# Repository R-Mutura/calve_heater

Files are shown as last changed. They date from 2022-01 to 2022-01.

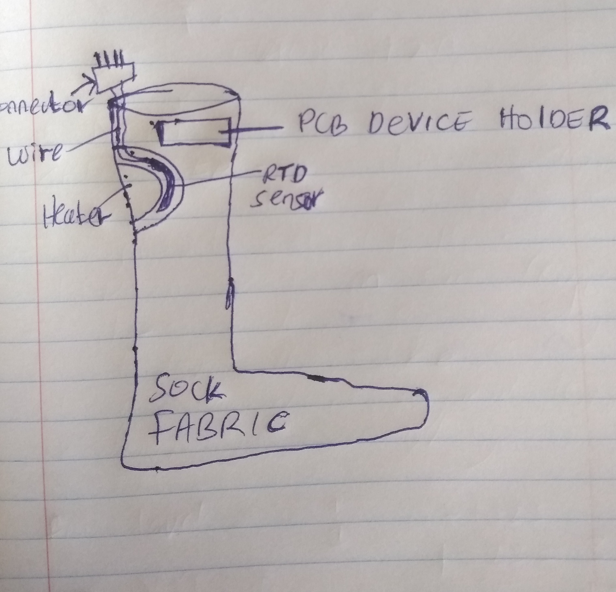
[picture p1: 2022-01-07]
hardware/ASSETS/IMG_20220107_123316.jpg

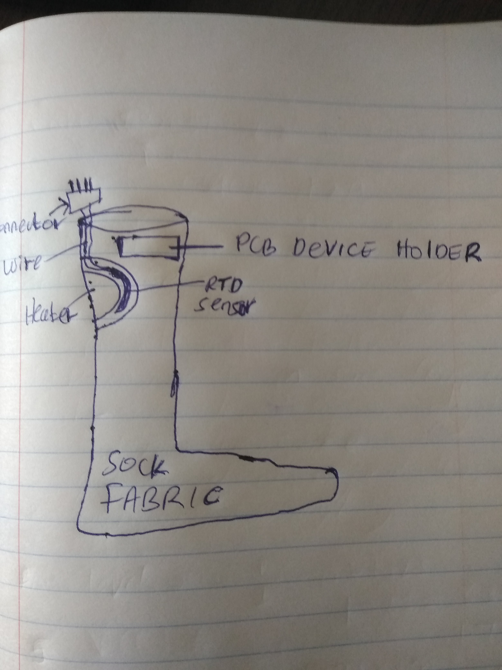
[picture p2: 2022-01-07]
hardware/ASSETS/IMG_20220107_123309.jpg

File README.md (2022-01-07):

# CALVE HEATER
This product features 3 main parts: the fabric containig a heater and  temperature RTD sensor embedded in it, a PCB that runs the heater and warming process and Firmware that is burnt in to the MCU located on the PCB assembly. 
The product features a modular approach where the controlling PCB can be plugged and unplugged from the fabric at will. It has a small form factor that allows it to be a hand held device that is powered via a Li-Po battery.

calve_heater

calve_heater 4

### How it works 🔧
THe PCB contains JST connectors from where the heater and temperature sensor are plugged into the board. Make sure thwy are plugged in. Press the ON button(left od USB) and the device wakes up and starsts the heating process. To turn off the device, Long press the ON button for about 1 sec. This will cause the device to go to sleep.
Temperature level setting is achieved via the use of the temperature button. (Button right of the USB). Default setting is at 40 degrees. Pressing it once increases the level to 44 deg, pressing it once again increases the level to 48 deg. Once at the highest level pressing the button again will take the level back to the initial  40 deg. The temperature level is indicated by use of the LED below the temperature button. 

- Green = 40deg
- Blue = 44deg
- Red = 48deg
<br>
The device uses PID control to warm up the fabric and maintain the desired temperature at all times ensuring safe.bumpless and comfortable use.
When the battery level gets too low the RED led flashes at 1 sec intervals indicating need for charging. 
the device is charged via the Micro-USB port. During charging, 2 leds below the on button are used for monitoring. Red is constantly on if its connected to power, and the Green LED indicates charging status:
- ON = CHarging
- OFF = Done charging <br>
<br>

# HARDWARE COMPONENTS
Heater [link](https://www.alibaba.com/product-detail/High-Temperature-Flexible-Ployimide-PI-Film_60627303766.html)   [link2](https://www.alibaba.com/product-detail/Thermostatic-electric-carbon-fiber-heating-element_62302051301.html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) <br>
Battery [link](https://www.indiamart.com/proddetail/lithium-ion-batteries-3-7v-2500mah-10433305048.html)  <br>
RTD sensor [link](https://www.digikey.com/en/products/detail/te-connectivity-measurement-specialties/R-8203/5277360)<br>
<br>
For the PCB components refer to the BOM folder in the hardware section.

# SAFETY
All the electrical components are on the PCB and can be disconnected in case of any critical situations by the user. Ensure to keep the device free from water and dust that may block the connectors. Disconnect the PCB device when washing the fabric. The Heater is a well made material wwith insulated wires to avoid shocking the user in amy way. When washing ensure not to cut, scrape or peel off any parts. Consider best practices [link](https://www.youtube.com/watch?v=5kIUcR_C9-A)

# BURNING BOOTLOADER AND FIRMWARE TO THE PCB
### Download the Files :arrow_down_small:
From this repo click on the download option at the code :arrow_double_down: 
- You will have two folders inside the main folder i.e 📁 Bootloader and  📁calve_heater_furmware
<br>
##  Burning bootload to the MCU :fire:
 <h3> Note: 
 DO THIS ON A WINDOWS OPERATING SYSTEM!!!
  </h3>
1) To do this you will need an older version of the arduino particularly version 1.6.9 find it here :link: [Old SoftwareReleases Arduino IDE](https://www.arduino.cc/en/main/OldSoftwareReleases) <br/>
2) Once you have it setup to burn the bootloader follow this tutotial keenly:link: [Burning Arduino Bootloader](https://create.arduino.cc/projecthub/techmirtz/arduino-without-external-clock-crystal-on-atmega328-d4fcc4) <br>
3) You can also use a USBASP to burn the bootloader. Note the above instruction will be used but instead of selecting arduino as ISP your programmer the USBASP is selected. 



[buy usbasp](https://aliexpress.ru/af/USBASP-USBISP-AVR-Programmer-USB.html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)
or here 
 :link: [buy usbasp](https://aliexpress.ru/item/32649685244.html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,searchweb201602_,searchweb201603_)
 <br/>
 
 ## Uploading the codes  :arrow_up:
 1) Open the 📁calve_heater_furmware Folder and open the INO file with your arduino
2) If you use Arduino as your programmer or an FTDI, Follow the instructions here from step 3: [Uploading Code](https://create.arduino.cc/projecthub/techmirtz/arduino-without-external-clock-crystal-on-atmega328-d4fcc4)
3) However if you are using a USBASP, Follow the following instructions:<br>
   a) Insert the ISP programmer cable socket onto ISP header. ...<br>
   b) Open Arduino IDE software. ...<br>
   c) Next, call out any example of source code. ...<br>
   d) Select “USBasp” from the Tools > Programmer menu.<br>
   e) Select “Upload using Programmer” from the File menu.<br>
 You can also explore more from the following tutorial :link:[How to Use USBasp Programmer with Arduino Boards](https://www.youtube.com/watch?v=ToKerwRR-70)

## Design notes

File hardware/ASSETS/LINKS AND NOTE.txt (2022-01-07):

FLEXIBLE HEATERS: 
COTTON TYPE HEATER:
https://www.alibaba.com/product-detail/China-factory-made-carbon-fiber-heating_62332728192.html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
https://www.alibaba.com/product-detail/Thermostatic-electric-carbon-fiber-heating-element_62302051301.html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
USED+++=====
https://www.alibaba.com/product-detail/High-Temperature-Flexible-Ployimide-PI-Film_60627303766.html  -0.4W

TEMP SENSOR:
https://www.digikey.com/en/products/detail/te-connectivity-measurement-specialties/R-8203/5277360
CAN EASILY BE PLACED IN THE FABRIC.

BATTERY:https://www.indiamart.com/proddetail/lithium-ion-batteries-3-7v-2500mah-10433305048.html

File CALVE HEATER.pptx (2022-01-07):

## CALVE HEATER

DETAILED ESCRIPTION

## PCB

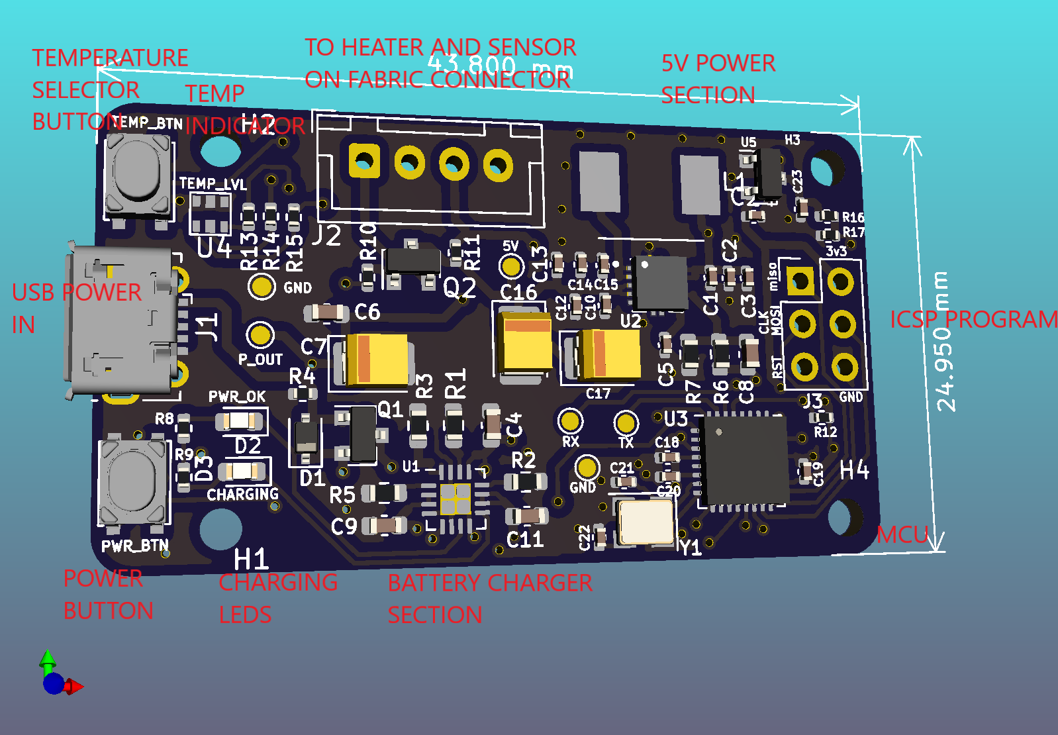
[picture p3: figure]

## PCB

- The USB port acts as the charging input. When charging the charging LEDs, green and Red are on. When done with charging, Only the red LED is on. (note the location of the charging LEDs.
- The Power button is used to turn on and off the device. Press once to turn on and long Press for 1 sec to turn off.
- Temperature selector button is used to set the temperature level for which the heater is to operate. Defult is 40 deg. Press once to increase the level to 44deg then again to 48 deg. Once at maximum pressing the button returns t=the temperature setting to the default 40deg.

## PCB

- The connector labeled J2 is used to connect the heater coil/element located off the board(in the fabric). As well as the temperature sensor. This allows the heater and sensor to be plugged in and removeable at will and depending on use.
- ICSP programmer are used to load the software to the board MCU as per the instruction in the github link.
- The MCU controls the heating of the board accordingly ensuring that it measures the temperature in of the heater using the connected sensor and maintains the heat as desired. It ensures that the desired temperature and over temperature conditions do not occur. this MCU control/drives the heater.
- The MCU as well reads the user settings and manages the LEDS indicators that inform the user.

## PCB

- EG when the battery is Low, the MCU causes the red LED to blink at a rate of 1 sec to indicate need for charging.
- Temperature indicator LED are 3 which will indicate the 3 temperature setting selected by the user:
- Green = 40deg low
- Blue = 44deg medium
- Red = 48deg high

## PCB

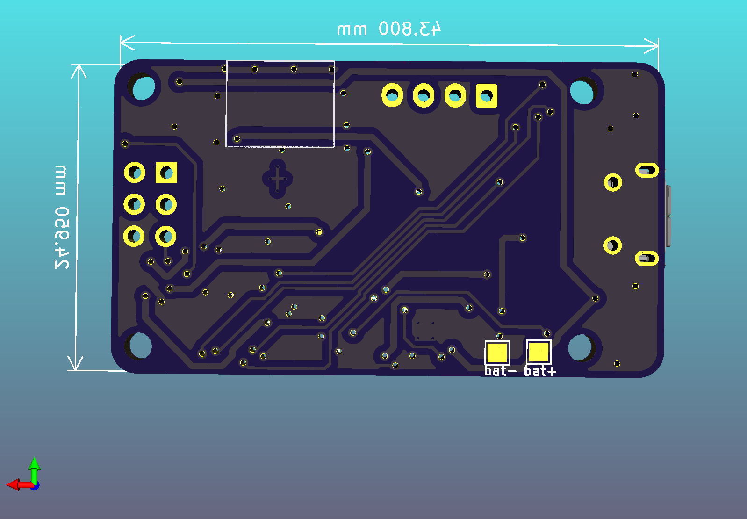
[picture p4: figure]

## BATTERY

- He battery is connected to the PCB via the bat+ and bat- pads shown above. These two terminal allow flexibility of connection and placement of the battery on any angle in a mechanical package.
- Battery type for use: https://www.indiamart.com/proddetail/lithium-ion-batteries-3-7v-2500mah-10433305048.html

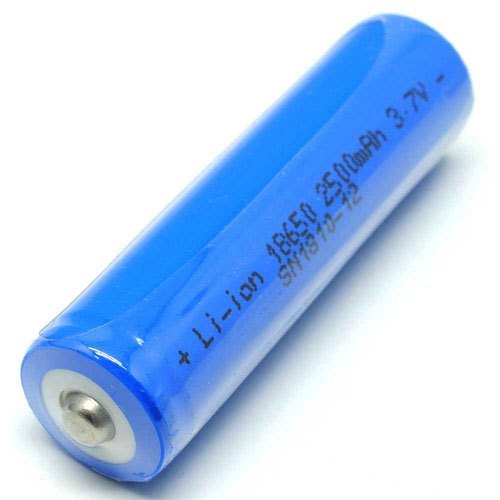
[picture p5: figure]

## BATTERY LIFE

- The design is kept simple and efficient as possible using low quiescent IC and MCUs. The heater power range is as well low with a about 100mA current consumption. Thus the total current consumption range for all the equipment in the PCB is about
- 100 heater + 100 MCU+ 50 Loses=250mA
- Battery capacity = 2500
- Total Hours of use = 2500/250 = 10Hrs approximate battery life.

## HEATER LAYOUT SKETCH

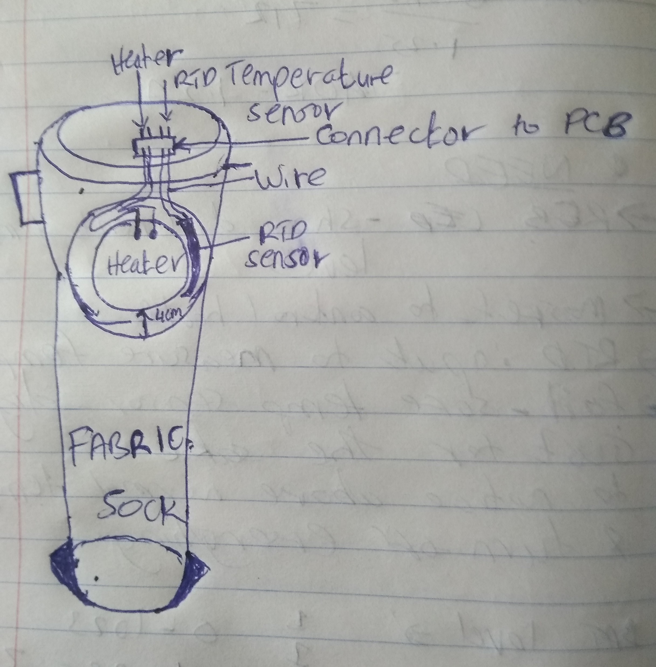
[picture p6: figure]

## HEATER SELECTION

- COTTON TYPE HEATER LINK : https://www.alibaba.com/product-detail/Thermostatic-electric-carbon-fiber-heating-element_62302051301.html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
- Flexible heater selection 2: https://www.alibaba.com/product-detail/High-Temperature-Flexible-Ployimide-PI-Film_60627303766.html

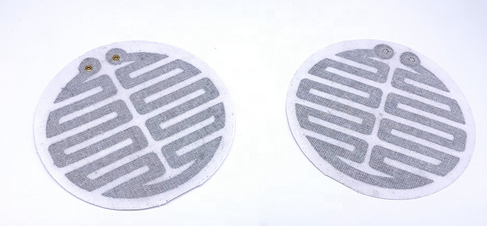
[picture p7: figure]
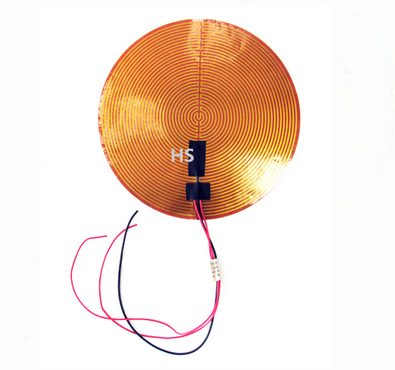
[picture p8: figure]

## TEMPERATURE SENSOR

- https://www.digikey.com/en/products/detail/te-connectivity-measurement-specialties/R-8203/5277360
- Flexible and bendable surface which is easy to integrate/place in a fabric

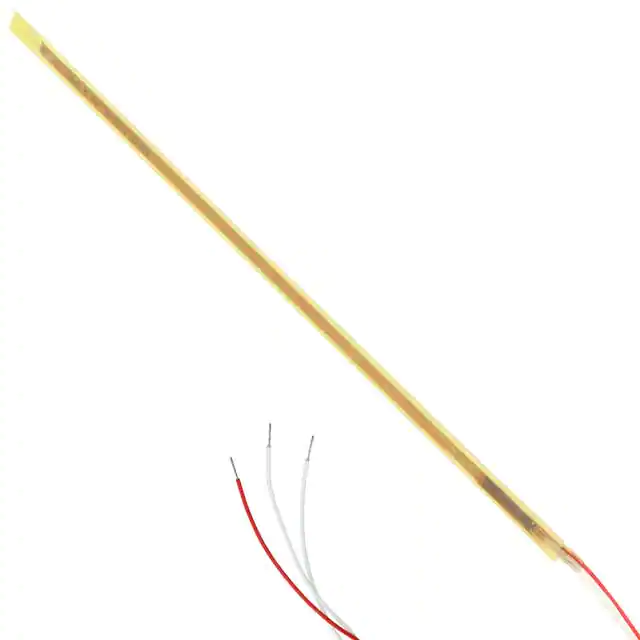
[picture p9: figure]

## SAFETY

- The product features a removeable PCB device which can there fore be kept odd any harmful conditions e.g. during washing.
- The heater elements by nature of there design are well insulated and suited to be used in fabrics and thus have good insulation resistant to corrosion and able to be bent and folded according to best practice in any electrically heated fabrics.
- The RTD sensor is well insulated as well and carries micro amperes of current which cannot lead to any form of sensation or shock to the user incase of any leakages. Making this product perfectly safe for use.

## CONCLUSION

- The product design utilizes existing components and materials that a re cheaply available making it affordable.
- The PCB design is of a small form factor and flexible thus making it very adaptable and to any changing conditions and uses.
- The battery life in this design is optimized via design of efficient software, hardware components and the heating process.
- Safety is integrated in the process from firmware design to prevent over temperature conditions and proper selection of heating and sensor elements.
- Rechargeable battery and proper indication has been achieved in the design as well.

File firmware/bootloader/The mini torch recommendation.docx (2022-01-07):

The mini torch recommendation

LED

1. R2835W-W5M-Q20 : https://www.luckylight.cn/en/products/lighting-led/mid-power-led/r2835w-w5m-q20/ (60mA 0.2W LED)__midpower range
2. https://www.digikey.com/en/products/filter/led-lighting-white/124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

Time IC

We ‘ll use ATMega32u chip which is present in Arduino Micro and Leonardo Arduino boards.

(We will have to introduce sleep function and the two buttons to act as the interrupt to wake up the IC once time needs to be set and also to wake up the IC to display clock time). Thus reduce power consumption significantly.

An RTC IC with a small form factor e.g. Maxim Integrated DS3231MZ+TRL which is also very accurate

Crystal oscillators for the atmega is not needed (configured to be the internal clock by the bootloader) and for the RTC=32KHz.

Boot loading instructions: https://www.instructables.com/Burn-a-New-Bootloader-Arduino-Pro-Mini/

LCD screen

The smallest OLED screen that uses I2C e.g. 0.69 inch screen https://africa.rsdelivers.com/product/midas/mcot096016ay-wi/midas-069in-white-passive-matrix-oled-display-96-x/8235948

Button to turn light on/off – Well use normal push buttons and implement a software toggle.

And to write to the output to turn on the LEDS, well use a MOSFET (N_MOS) WST02N10: https://lcsc.com/product-detail/MOSFETs_Winsok-Semicon-WST02N10_C148341.html

Also for the time setting button we will use a normal button in conjunction with ezButton library to handle different event like button press, double press and long press

Battery

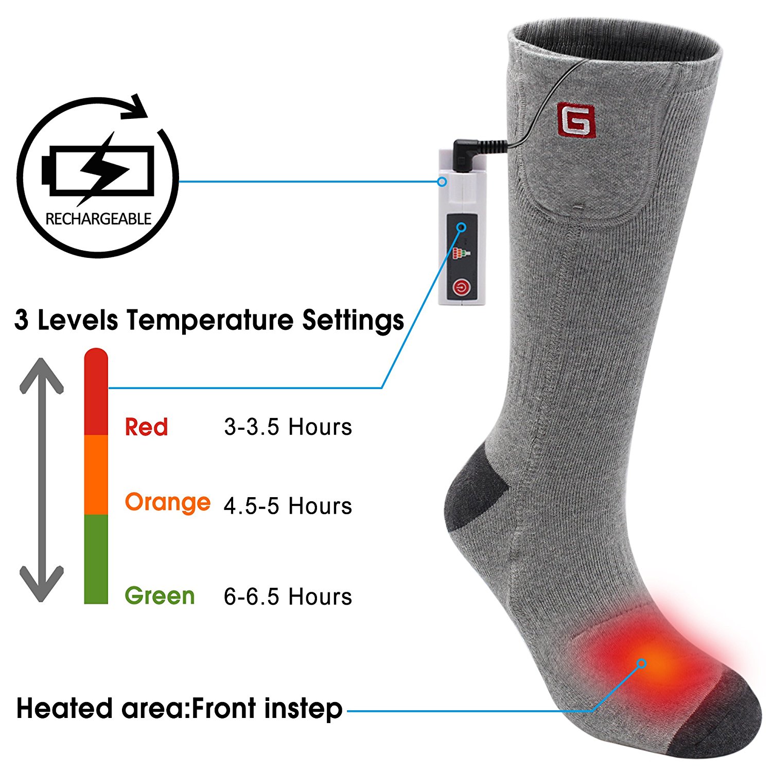
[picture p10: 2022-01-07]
hardware/ASSETS/Global-Vasion-Rechargeable-Battery-Heated-Socks-02.jpg

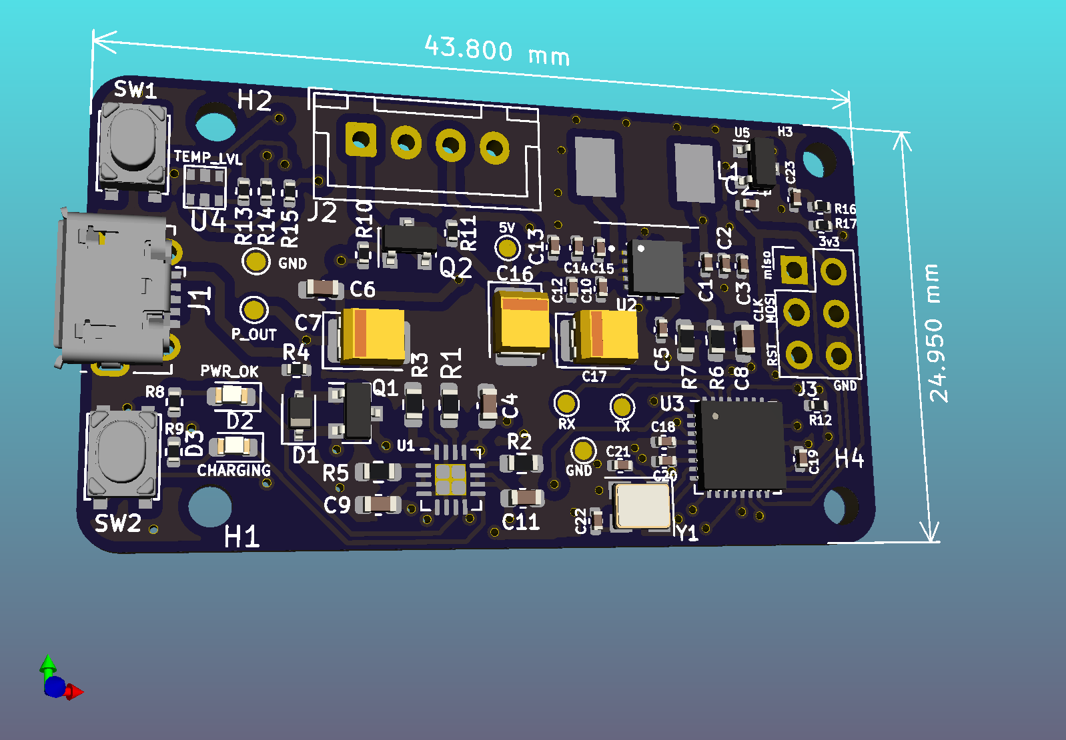
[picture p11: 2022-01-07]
hardware/png/calve_heater 6.png

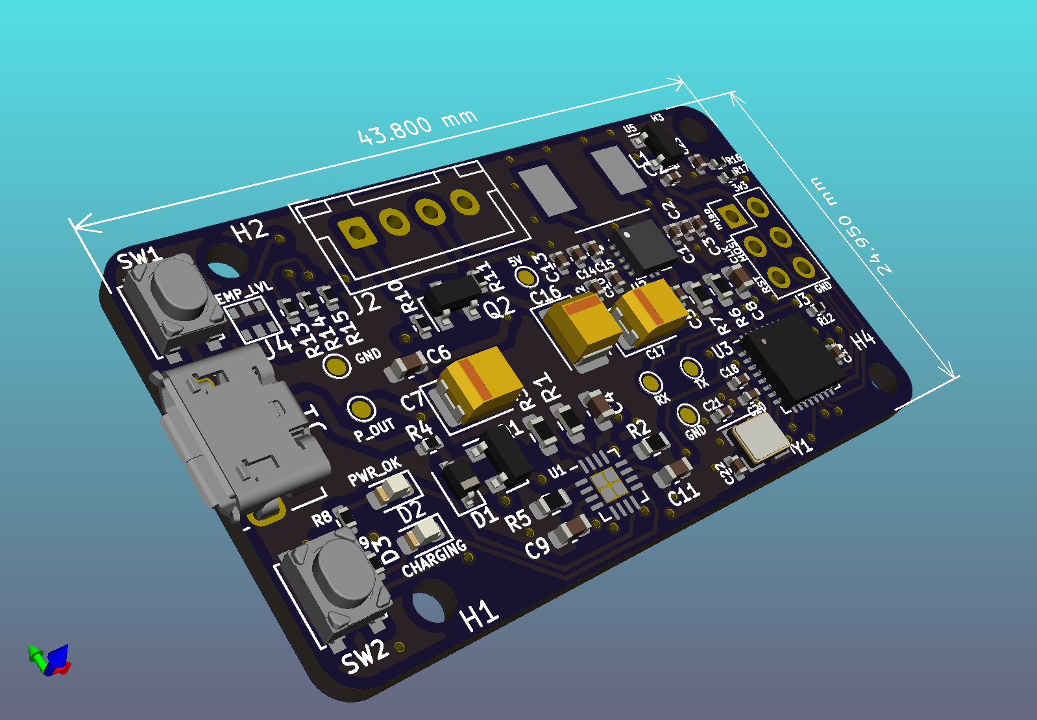
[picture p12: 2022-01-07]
hardware/png/calve_heater 4.png

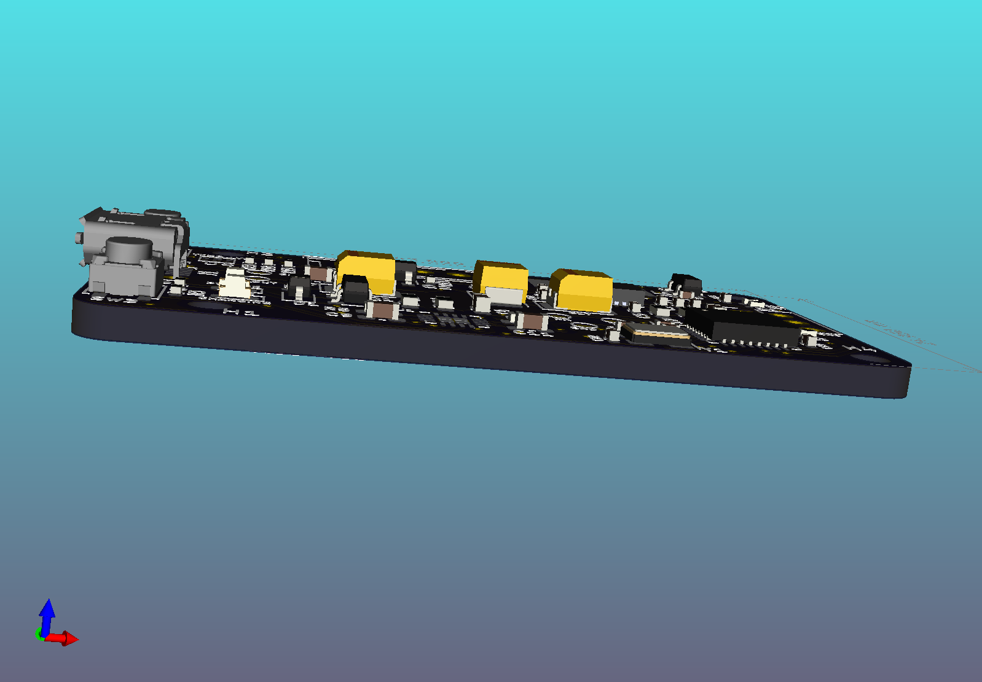
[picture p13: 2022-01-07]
hardware/png/calve_heater 3.png

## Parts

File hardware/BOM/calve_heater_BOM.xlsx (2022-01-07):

Reference | Value | Footprint | MPN | Vendor | QTY
C1-C3, C23, C24 | 10u | Capacitor_SMD:C_0402_1005Metric | JMK105CBJ106MV-F | LCSC | 5
C4 | 1u | Capacitor_SMD:C_0603_1608Metric | FS18B105K160PBG | LCSC | 1
C5 | 10n | Capacitor_SMD:C_0402_1005Metric | C0402X7R103K500NTB | LCSC | 1
C6 | 4.7u | Capacitor_SMD:C_0603_1608Metric | GRM188R61C475KE11D | LCSC | 1
C8 | 18p | Capacitor_SMD:C_0603_1608Metric | CGA3E2C0G1H180JT0Y0N | LCSC | 1
C9, C11 | 10u | Capacitor_SMD:C_0603_1608Metric | CL10A106MA8NRNC | LCSC | 2
C10, C12-C15 | 4.7u | Capacitor_SMD:C_0402_1005Metric | EDK105BBJ475MVLF | LCSC | 5
C7, C16, C17 | 100u | Capacitor_Tantalum_SMD:CP_EIA-3528-21_Kemet-B | CA45-B-10V-100uF-M | LCSC | 3
C18-C20 | 100nF | Capacitor_SMD:C_0402_1005Metric | C0402X7R104K160NTB | LCSC | 3
C21, C22 | 22pF | Capacitor_SMD:C_0402_1005Metric | GRM1555C1H220JA01D | LCSC | 2
D1 | D_Schottky_Small | Diode_SMD:D_SOD-323 | BAT60B | LCSC | 1
D2 | GREEN | LED_SMD:LED_0603_1608Metric | HSMG-C190 | Digikey | 1
D3 | RED | LED_SMD:LED_0603_1608Metric | LTST-C190KRKT | Digikey | 1
J1 | USB_B_Micro | Connector_USB:USB_Micro-B_Molex-105017-0001 | 105017-0001 | Digikey | 1
J2 | Conn_out | Connector_JST:JST_XH_B4B-XH-A_1x04_P2.50mm_Vertical | S4B-XH-SM4-TB(LF)(SN) | Digikey | 1
J3 | ICSP_HEADER | Connector_PinHeader_2.54mm:PinHeader_2x03_P2.54mm_Vertical | C65114 | LCSC | 1
L1 | 1.5uH | greencharge-footprints:MWSA0518S-1R5MT | MWSA0518S-1R5MT | LCSC | 1
Q1 | FDN338P-NL | Package_TO_SOT_SMD:SOT-23 | AP3401 | LCSC | 1
Q2 | SI2304BDS-T1-GE3 | Package_TO_SOT_SMD:SOT-23 | SI2304BDS-T1-GE3 | LCSC | 1
R1 | 50k | Resistor_SMD:R_0603_1608Metric | RC0603FR-0747KL | LCSC | 1
R2 | 1.07k | Resistor_SMD:R_0603_1608Metric | RCT031K07FLF | LCSC | 1
R3 | 750R | Resistor_SMD:R_0603_1608Metric | AECR0603F750RK9 | LCSC | 1
R4 | 10k | Resistor_SMD:R_0402_1005Metric | RC0402FR-7W10KL | LCSC | 1
R5 | 10k | Resistor_SMD:R_0603_1608Metric | ERJPA3J103V | LCSC | 1
R6 | 402k | Resistor_SMD:R_0603_1608Metric | 0603WAF4023T5E | LCSC | 1
R7 | 100k | Resistor_SMD:R_0603_1608Metric | RC0603FR-07100KL | LCSC | 1
R8, R9 | 1k | Resistor_SMD:R_0402_1005Metric | RC-02W1001FT | LCSC | 2
R10, R11 | 150R | Resistor_SMD:R_0402_1005Metric | 0402WGF1500TCE | LCSC | 2
R12 | 4.7K | Resistor_SMD:R_0402_1005Metric | RC0402FR-074K7L | LCSC | 1
R13-R17 | 1K | Resistor_SMD:R_0402_1005Metric | RC-02W1001FT | LCSC | 5
SW1, SW2 | SW_Push | greencharge-footprints:SKRPACE010 | SKRPACE010 | LCSC | 2
U1 | BQ24075RGT | Package_DFN_QFN:VQFN-16-1EP_3x3mm_P0.5mm_EP1.68x1.68mm_ThermalVias | BQ24075RGTR | LCSC | 1
U2 | TPS61230DRCR | greencharge-footprints:VREG_V62_16624-01YE | TPS61230DRCR | LCSC | 1
U3 | ATmega328P-MU | Package_DFN_QFN:QFN-32-1EP_5x5mm_P0.5mm_EP3.1x3.1mm | ATmega328P-MU | Digipart | 1
U4 | EAST1616RGBA8 | greencharge-footprints:EAST1616RGBA8 | EAST1616RGBA8 | Digikey | 1
U5 | LM1117-3.3 | Package_TO_SOT_SMD:SOT-23 | LP3986-33B3F | LCSC | 1
Y1 | X322516MOB4SI | Crystal:Crystal_SMD_EuroQuartz_MT-4Pin_3.2x2.5mm | X322516MOB4SI | LCSC | 1

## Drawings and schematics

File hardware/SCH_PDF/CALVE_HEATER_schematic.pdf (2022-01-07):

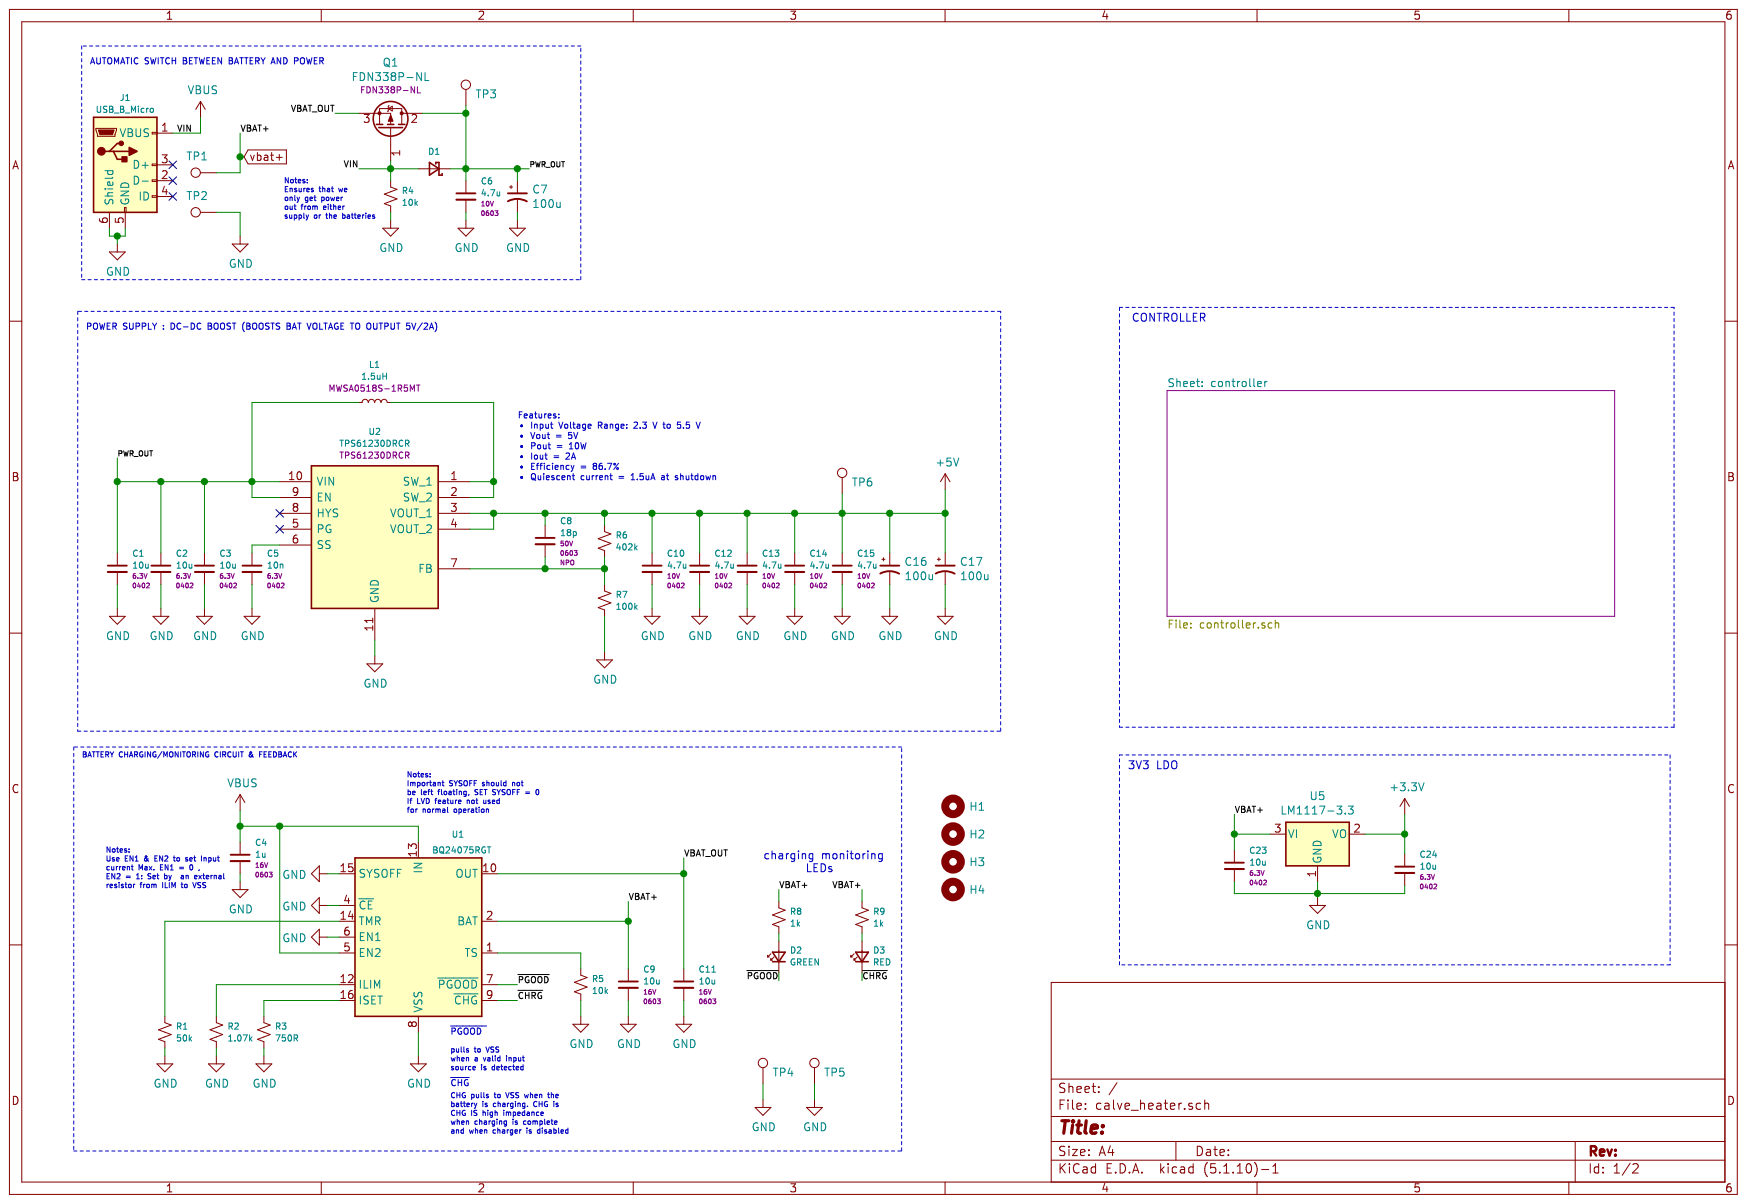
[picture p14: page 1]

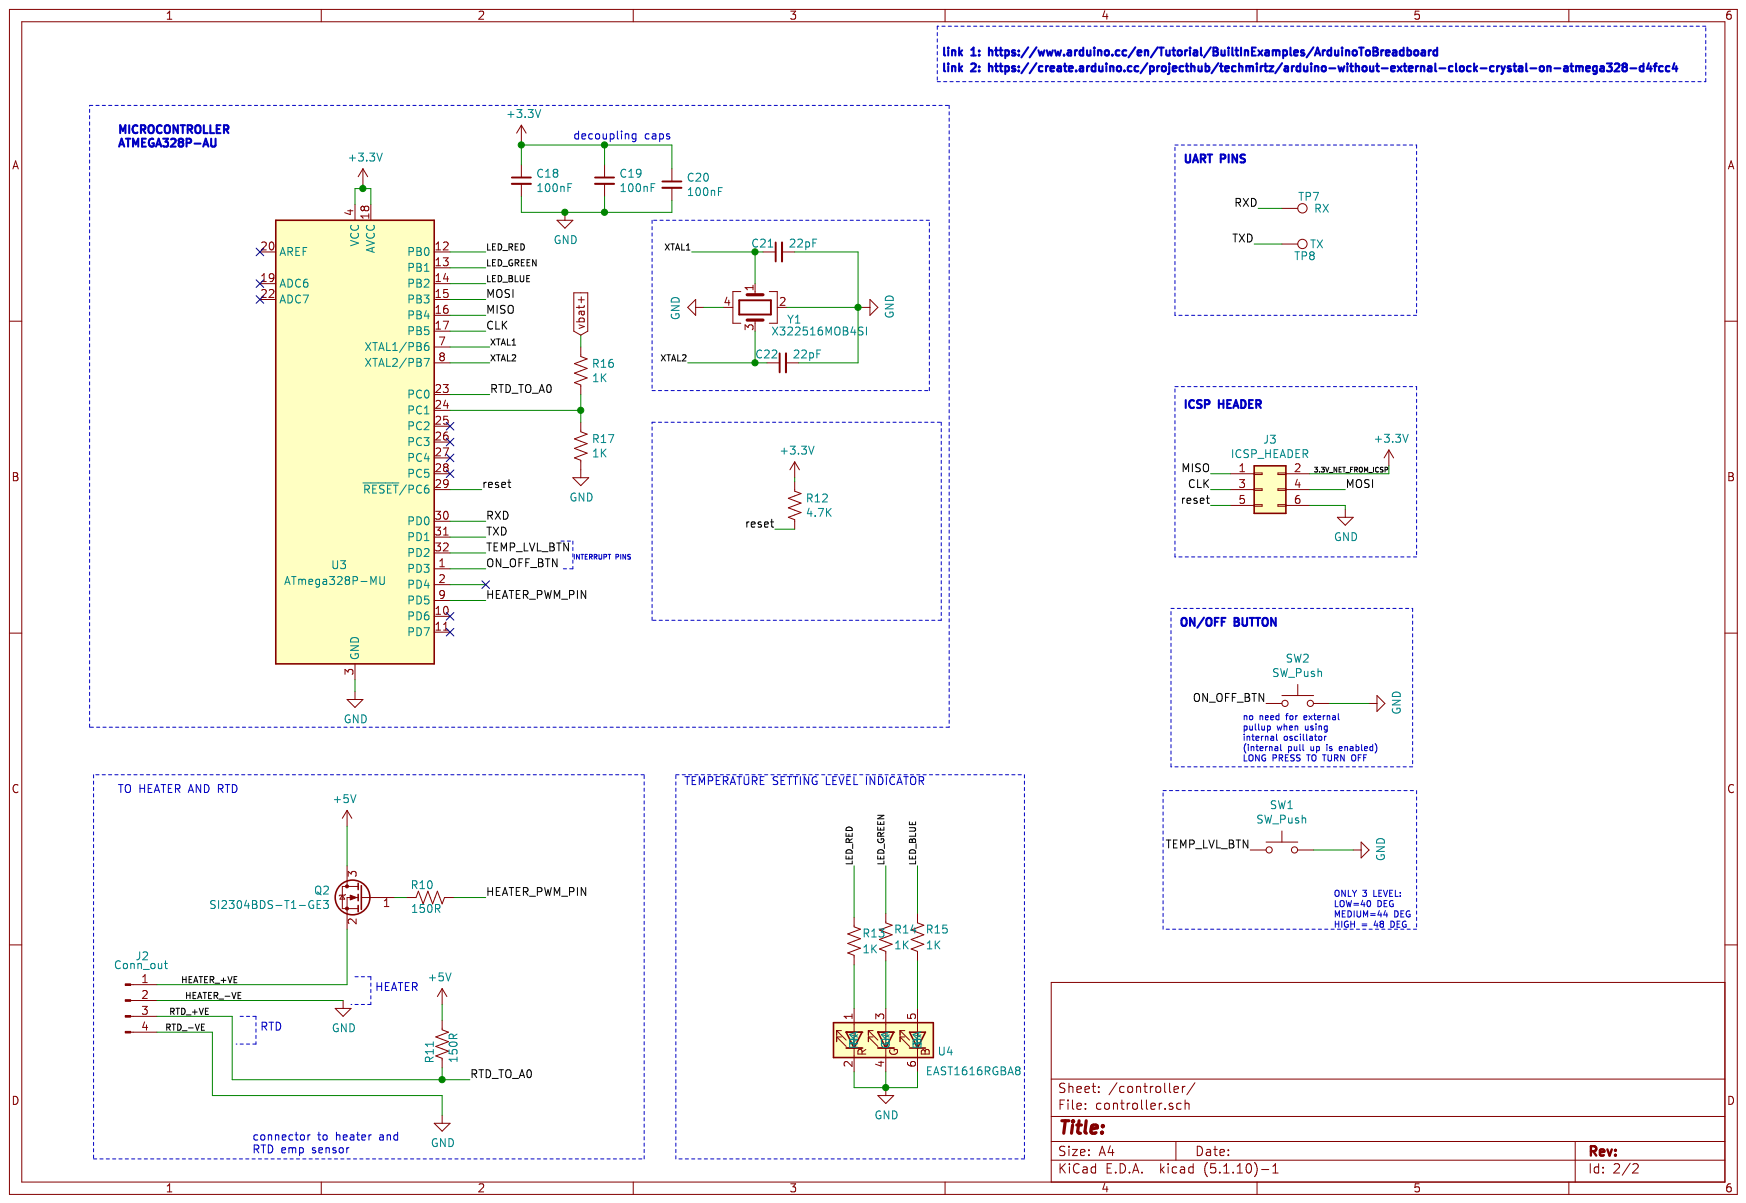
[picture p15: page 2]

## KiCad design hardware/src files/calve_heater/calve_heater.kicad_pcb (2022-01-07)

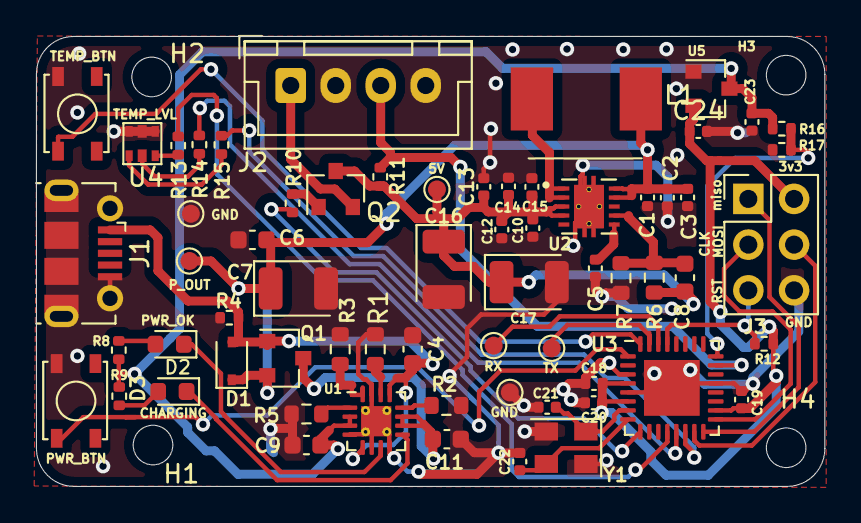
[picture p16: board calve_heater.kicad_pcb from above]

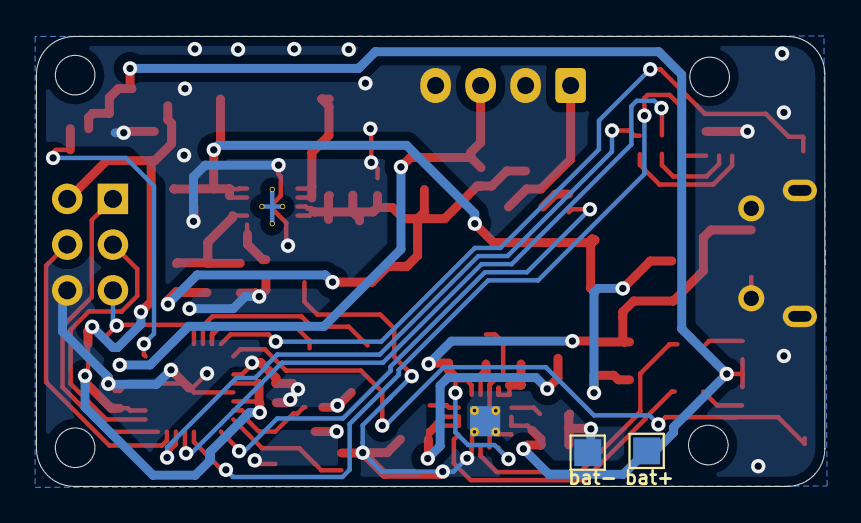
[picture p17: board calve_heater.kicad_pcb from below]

Board: 2 copper layers, 43.8 x 25.0 mm, 70 parts (2 on the bottom side), 39 nets.

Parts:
5V: TestPoint; TestPoint_Pad_D1.0mm
C1, C2, C3, C23, C24: 10u; C_0402_1005Metric
C4: 1u; C_0603_1608Metric
C5: 10n; C_0402_1005Metric
C6: 4.7u; C_0603_1608Metric
C7, C16, C17: 100u; CP_EIA-3528-21_Kemet-B
C8: 18p; C_0603_1608Metric
C9, C11: 10u; C_0603_1608Metric
C10, C12, C13, C14, C15: 4.7u; C_0402_1005Metric
C18, C19, C20: 100nF; C_0402_1005Metric
C21, C22: 22pF; C_0402_1005Metric
D1: D_Schottky_Small; D_SOD-323
D2: GREEN; LED_0603_1608Metric
D3: RED; LED_0603_1608Metric
GND: TestPoint; TestPoint_Pad_D1.0mm
GND#2: TestPoint; TestPoint_Pad_D1.0mm
H1, H2, H3, H4: MountingHole; MountingHole_2.2mm_M2_ISO14580
J1: USB_B_Micro; USB_Micro-B_Molex-105017-0001
J2: Conn_out; JST_XH_B4B-XH-A_1x04_P2.50mm_Vertical
J3: ICSP_HEADER; PinHeader_2x03_P2.54mm_Vertical
L1: 1.5uH; MWSA0518S-1R5MT
PWR_BTN: SW_Push; SKRPACE010
P_OUT: TestPoint; TestPoint_Pad_D1.0mm
Q1: FDN338P-NL; SOT-23
Q2: SI2304BDS-T1-GE3; SOT-23
R1: 50k; R_0603_1608Metric
R2: 1.07k; R_0603_1608Metric
R3: 750R; R_0603_1608Metric
R4: 10k; R_0402_1005Metric
R5: 10k; R_0603_1608Metric
R6: 402k; R_0603_1608Metric
R7: 100k; R_0603_1608Metric
R8, R9: 1k; R_0402_1005Metric
R10, R11: 150R; R_0402_1005Metric
R12: 4.7K; R_0402_1005Metric
R13, R14, R15, R16, R17: 1K; R_0402_1005Metric
RX: RX; TestPoint_Pad_D1.0mm
TEMP_BTN: SW_Push; SKRPACE010
TX: TX; TestPoint_Pad_D1.0mm
U1: BQ24075RGT; VQFN-16-1EP_3x3mm_P0.5mm_EP1.68x1.68mm_ThermalVias
U2: TPS61230DRCR; VREG_V62_16624-01YE
U3: ATmega328P-MU; QFN-32-1EP_5x5mm_P0.5mm_EP3.1x3.1mm
U4: EAST1616RGBA8
U5: LM1117-3.3; SOT-23
Y1: X322516MOB4SI; Crystal_SMD_EuroQuartz_MT-4Pin_3.2x2.5mm
bat+: TestPoint; TestPoint_Pad_1.5x1.5mm
bat-: TestPoint; TestPoint_Pad_1.5x1.5mm

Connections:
+3V3: C18.1, C19.1, C20.1, C24.1, J3.2, R12.1, U3.4, U3.6, U3.18, U5.2
+5V: 5V.1, C8.1, C10.1, C12.1, C13.1, C14.1, C15.1, C16.1, C17.1, Q2.3, R6.1, R11.2, U2.3, U2.4
/PWR_OUT: C1.1, C2.1, C3.1, C6.1, C7.1, D1.1, L1.1, P_OUT.1, Q1.2, U2.9, U2.10
/VBAT_OUT: C11.1, Q1.3, U1.10, U1.11
/controller/CLK: J3.3, U3.17
/controller/HEATER_+VE: J2.1, Q2.2
/controller/HEATER_PWM_PIN: R10.2, U3.9
/controller/LED_BLUE: R15.1, U3.14
/controller/LED_GREEN: R14.1, U3.13
/controller/LED_RED: R13.1, U3.12
/controller/MISO: J3.1, U3.16
/controller/MOSI: J3.4, U3.15
/controller/ON_OFF_BTN: PWR_BTN.1, U3.1
/controller/RTD_+VE: J2.3, R11.1, U3.23
/controller/RXD: RX.1, U3.30
/controller/TEMP_LVL_BTN: TEMP_BTN.1, U3.32
/controller/TXD: TX.1, U3.31
/controller/XTAL1: C21.1, U3.7, Y1.1
/controller/XTAL2: C22.1, U3.8, Y1.3
/controller/reset: J3.5, R12.2, U3.29
/~CHRG: D3.1, U1.9
/~PGOOD: D2.1, U1.7
GND: C1.2, C2.2, C3.2, C4.2, C5.2, C6.2, C7.2, C9.2, C10.2, C11.2, C12.2, C13.2, C14.2, C15.2, C16.2, C17.2, C18.2, C19.2, C20.2, C21.2, C22.2, C23.2, C24.2, GND.1, GND#2.1, J1.5, J1.6, J2.2, J2.4, J3.6, PWR_BTN.2, R1.2, R2.2, R3.2, R4.2, R5.2, R7.2, R17.2, TEMP_BTN.2, U1.4, U1.6, U1.8, U1.15, U1.17, U2.11, U3.3, U3.5, U3.21, U3.33, U4.2, U4.4, U4.6, U5.1, Y1.2, Y1.4, bat-.1
unnamed: C5.1, U2.6
unnamed: C8.2, R6.2, R7.1, U2.7
unnamed: D2.2, R8.2
unnamed: D3.2, R9.2
unnamed: L1.2, U2.1, U2.2
unnamed: Q2.1, R10.1
unnamed: R1.1, U1.14
unnamed: R2.1, U1.12
unnamed: R3.1, U1.16
unnamed: R5.1, U1.1
unnamed: R13.2, U4.1
unnamed: R14.2, U4.3
unnamed: R15.2, U4.5
unnamed: R16.2, R17.1, U3.24
VBUS: C4.1, D1.2, J1.1, Q1.1, R4.1, U1.5, U1.13
vbat+: C9.1, C23.1, R8.1, R9.1, R16.1, U1.2, U1.3, U5.3, bat+.1

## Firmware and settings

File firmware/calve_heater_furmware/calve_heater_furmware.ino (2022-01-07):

#include <Arduino.h>
#include <OneButton.h>
#include "LowPower.h"

//initialize the 2 buttons
#define TEMP_LVL_BTN 3  //PD3
   OneButton btn = OneButton(
        TEMP_LVL_BTN,  // Input pin for the button
        true,        // Button is active LOW
        true         // Enable internal pull-up resistor 
      );
 #define ON_OFF_BTN 2  //PD2
   OneButton btn_A = OneButton(
        ON_OFF_BTN,  // Input pin for the button
        true,        // Button is active LOW
        true         // Enable internal pull-up resistor 
      );
 //temperature constants
 const int SensorValueLow = 463; 
const int SensorValueDiff = 36; // differance between high and low sensor value
const int TempValueDiff = 42; // differance between high and low Temp value
const int TempValueLow = 9;

 //defined constants
 int sleep_flag=0;
 int temp_level=0;
float PID_error = 0;
float previous_error = 0;
float elapsedTime, Time, timePrev;
float PID_value = 0;
long currentMillis=0;
 int heater=5;
 int rtd   =A0;
 int red   =8;
 int green =9;
 int blue =10;
 //PID variables
//PID constants
int kp = 90;   int ki = 30;   int kd = 80;
int PID_p = 0;    int PID_i = 0;    int PID_d = 0;

long my_Delay= 50;//50ms refresh rate
int toggle_delay=1000;
long current_toggle=0;
void setup() {
  // put your setup code here, to run once:
  //initialize button parameters
   btn.setDebounceTicks(30);//deboumce time
   btn.setClickTicks(250);//click period to register double press
   btn. setPressTicks(800);//period to register long press
   //button press handles
   btn.attachClick(handleClick);
   
   btn_A.attachLongPressStart(handleLongpress);

    //handle input/output setup
   pinMode(heater, OUTPUT);
   pinMode(red, OUTPUT);
   pinMode(green, OUTPUT);
   pinMode(blue, OUTPUT);
   pinMode(rtd, INPUT);
}

void loop() {
  // put your main code here, to run repeatedly:
  if(sleep_flag==1){
    attachInterrupt(1, wakeUp, LOW);//attach interrupt pin 1 of the atmeaga
  LowPower.powerDown(SLEEP_FOREVER, ADC_OFF, BOD_OFF);
    }
    
   detachInterrupt(0);
   btn.tick();
     
   //get temperature level
   float temperature=set_temperature(temp_level);//set temperature
   float temperature_read =read_rtd();
   if(millis()-currentMillis>= my_Delay){
   temp_control(temperature,temperature_read);
   }
  //monitor battery level
  int bat_level = analogRead(A1);
  if(bat_level<543){
    //toggle the red led on off every cycle to alert the user
    if(millis()-current_toggle>= toggle_delay){
      digitalWrite(red, !digitalRead(red));
      }
    }
}

void handleClick(){
  if(temp_level<3){
    temp_level++;
    }
    else{
      temp_level=0;
      }
  }
  
void wakeUp()
{
  sleep_flag=0;
    // Just a handler for the pin interrupt.
}
void handleLongpress(){
  sleep_flag=1;
  }  
  int set_temperature(int level){
    if(level==0){
      digitalWrite(green, HIGH);
      digitalWrite(red, LOW);
      digitalWrite(blue, LOW);
      return 40; //return that the temperature is 40 degrees
      }
    else if(level==1){
      digitalWrite(blue, HIGH);
      digitalWrite(red, LOW);
      digitalWrite(green, LOW);
      return 44;
      }
     else{
      digitalWrite(red, HIGH);
      digitalWrite(green, LOW);
      digitalWrite(blue, LOW);
      return 48;
      }
    } 
 void temp_control(float temperature, float temperature_actual){
    PID_error = temperature - (temperature_actual + 3);
    PID_p = 0.01*kp * PID_error;
  //Calculate the I value in a range on +-3
  PID_i = 0.01*PID_i + (ki * PID_error);
   timePrev = Time;                            // the previous time is stored before the actual time read
  Time = millis();                            // actual time read
  elapsedTime = (Time - timePrev) / 1000; 
  //Now we can calculate the D calue
  PID_d = 0.01*kd*((PID_error - previous_error)/elapsedTime);
  //Final total PID value is the sum of P + I + D
  PID_value = PID_p + PID_i + PID_d;

  //We define PWM range between 0 and 255
  if(PID_value < 0)
  {    PID_value = 0;    }
  if(PID_value > 255)  
  {    PID_value = 255;  }
  //Now we can write the PWM signal to the mosfet on digital heater pin 
  //Since we activate the MOSFET with a 1 to the gate, we write PID value directly
  analogWrite(heater,PID_value);
  previous_error = PID_error;     //Remember to store the previous error for next loop.
    currentMillis = millis();//to be used to set refresh rate of the loop
    }
    
float read_rtd(){
  int sensorValue = analogRead(rtd);
  int Temp = sensorValue-SensorValueLow;
  Temp = Temp/SensorValueDiff;
  Temp = Temp*TempValueDiff;
  Temp = Temp+TempValueLow; 
  return Temp;   
      }

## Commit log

2022-01-07 update on calve design
    [calve_heater-B_Cu.gbr, calve_heater-B_Mask.gbr, calve_heater-B_Paste.gbr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]
2022-01-07 updated bom
    [calve_heater_BOM.xlsx]
